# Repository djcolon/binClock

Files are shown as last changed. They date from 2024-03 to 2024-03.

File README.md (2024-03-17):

# binClock

**Daniel Colon - 19/02/2024**

binClock

A binary clock using an ESP8266 board with some 74HC595 shift registers to
drive LEDs.
Uses NTP to get time over the network.
Also has modes to show it's IP and ping-pong a led back and forth.

Built with an ESP32-C3 Mini, which I bought for 1.83
[here](https://www.aliexpress.com/item/1005005967641936.html)

[Built using PlatformIO](https://platformio.org/)

## Testing

To run tests you need to have configured the platformIO native environment.
See the [platformIO guides](https://piolabs.com/blog/insights/unit-testing-part-1.html)
for more detail.

After installation, run tests by navigating to `native > advanced > test` in the
platformIO sidebar.

## Board

The PCB and schematic do not include the LEDs. An 8-pin connector is offered,
as well as a mounting hole for the LED ground. The intention is to use a piece
of 2mm solid core copper to attach the LED ground to, with wires leading to an
8 pin connector which will plug into the PCB. The entire board can be powered
via the ESP32's USB-C connector.

## Images

The assembled binClock:

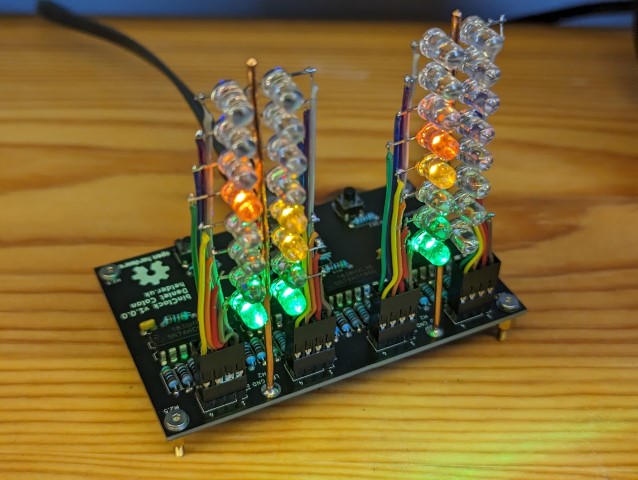
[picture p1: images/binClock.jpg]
The assembled binClock


The prototype:

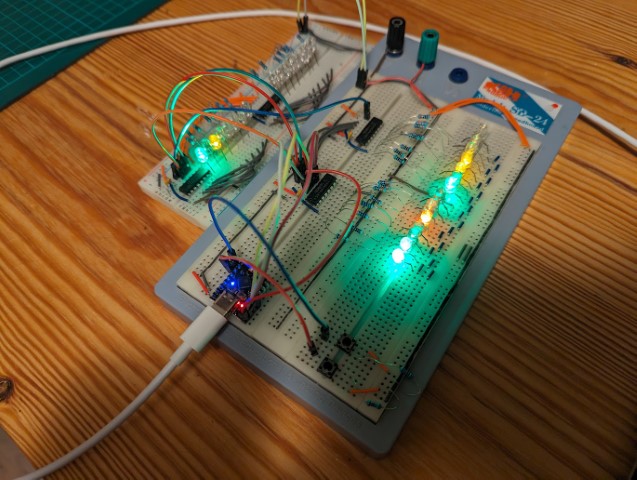
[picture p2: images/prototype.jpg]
The prototype


The schematic:

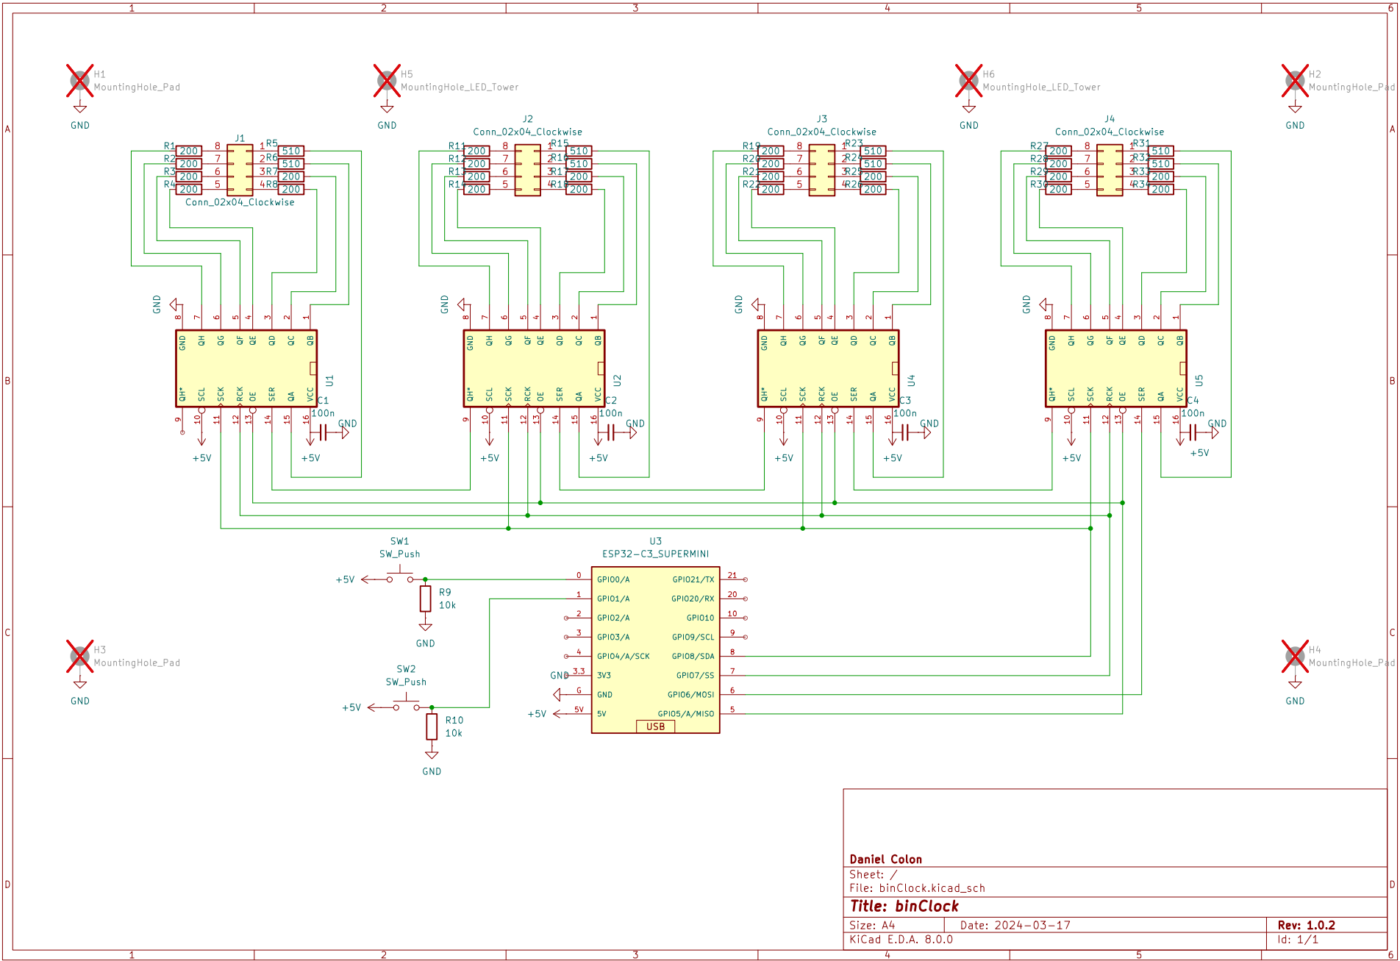
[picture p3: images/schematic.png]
The schematic


A preview of the PCB front:

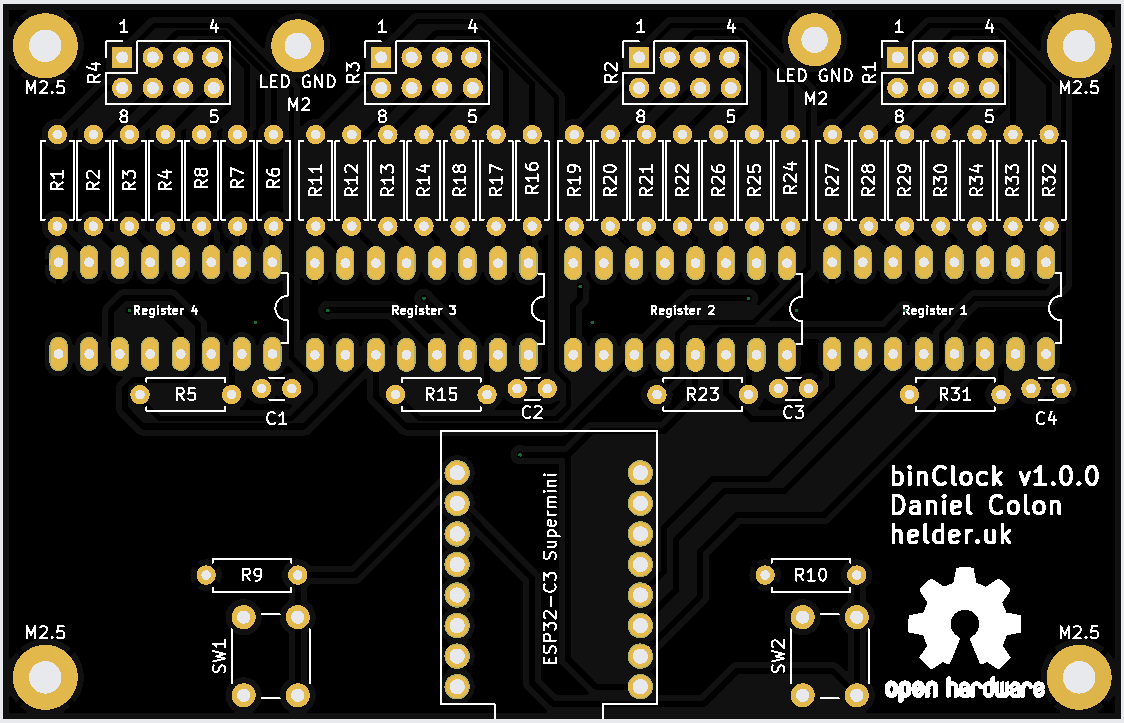
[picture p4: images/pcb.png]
The PCB preview


The devboard pinout.

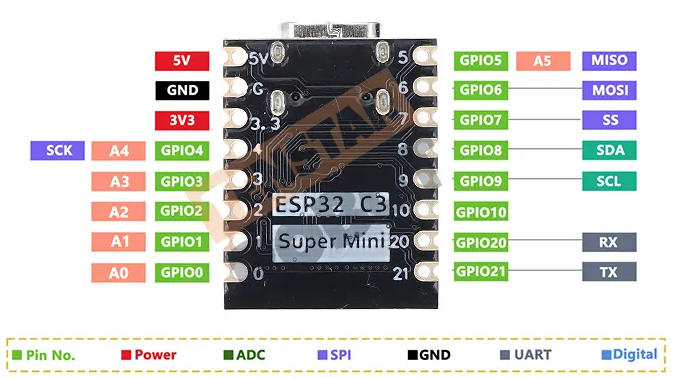
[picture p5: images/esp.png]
The devboard pinout


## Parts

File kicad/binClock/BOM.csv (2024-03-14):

Reference | Value | Qty | DNP
C1,C2,C3,C4 | 100n | 4
J1,J2,J3,J4 | Conn_02x04_Clockwise | 4
R1,R2,R3,R4,R7,R8,R11,R12,R13,R14,R17,R18,R19,R20,R21,R22,R25,R26,R27,R28,R29,R30,R33,R34 | 200 | 24
R5,R6,R15,R16,R23,R24,R31,R32 | 510 | 8
R9,R10 | 10k | 2
SW1,SW2 | SW_Push | 2
U1,U2,U4,U5 | 74HC595N | 4
U3 | ESP32-C3_SUPERMINI | 1

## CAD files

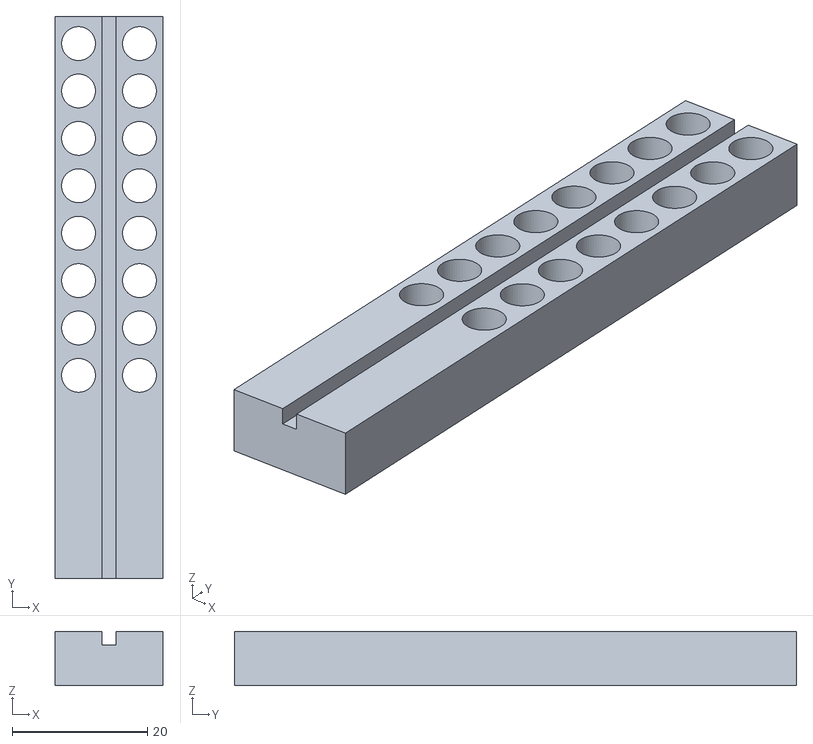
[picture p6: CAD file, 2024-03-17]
physical/tree_template.stl
16.0 x 83.0 x 8.00

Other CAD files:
physical/tree_template.f3d

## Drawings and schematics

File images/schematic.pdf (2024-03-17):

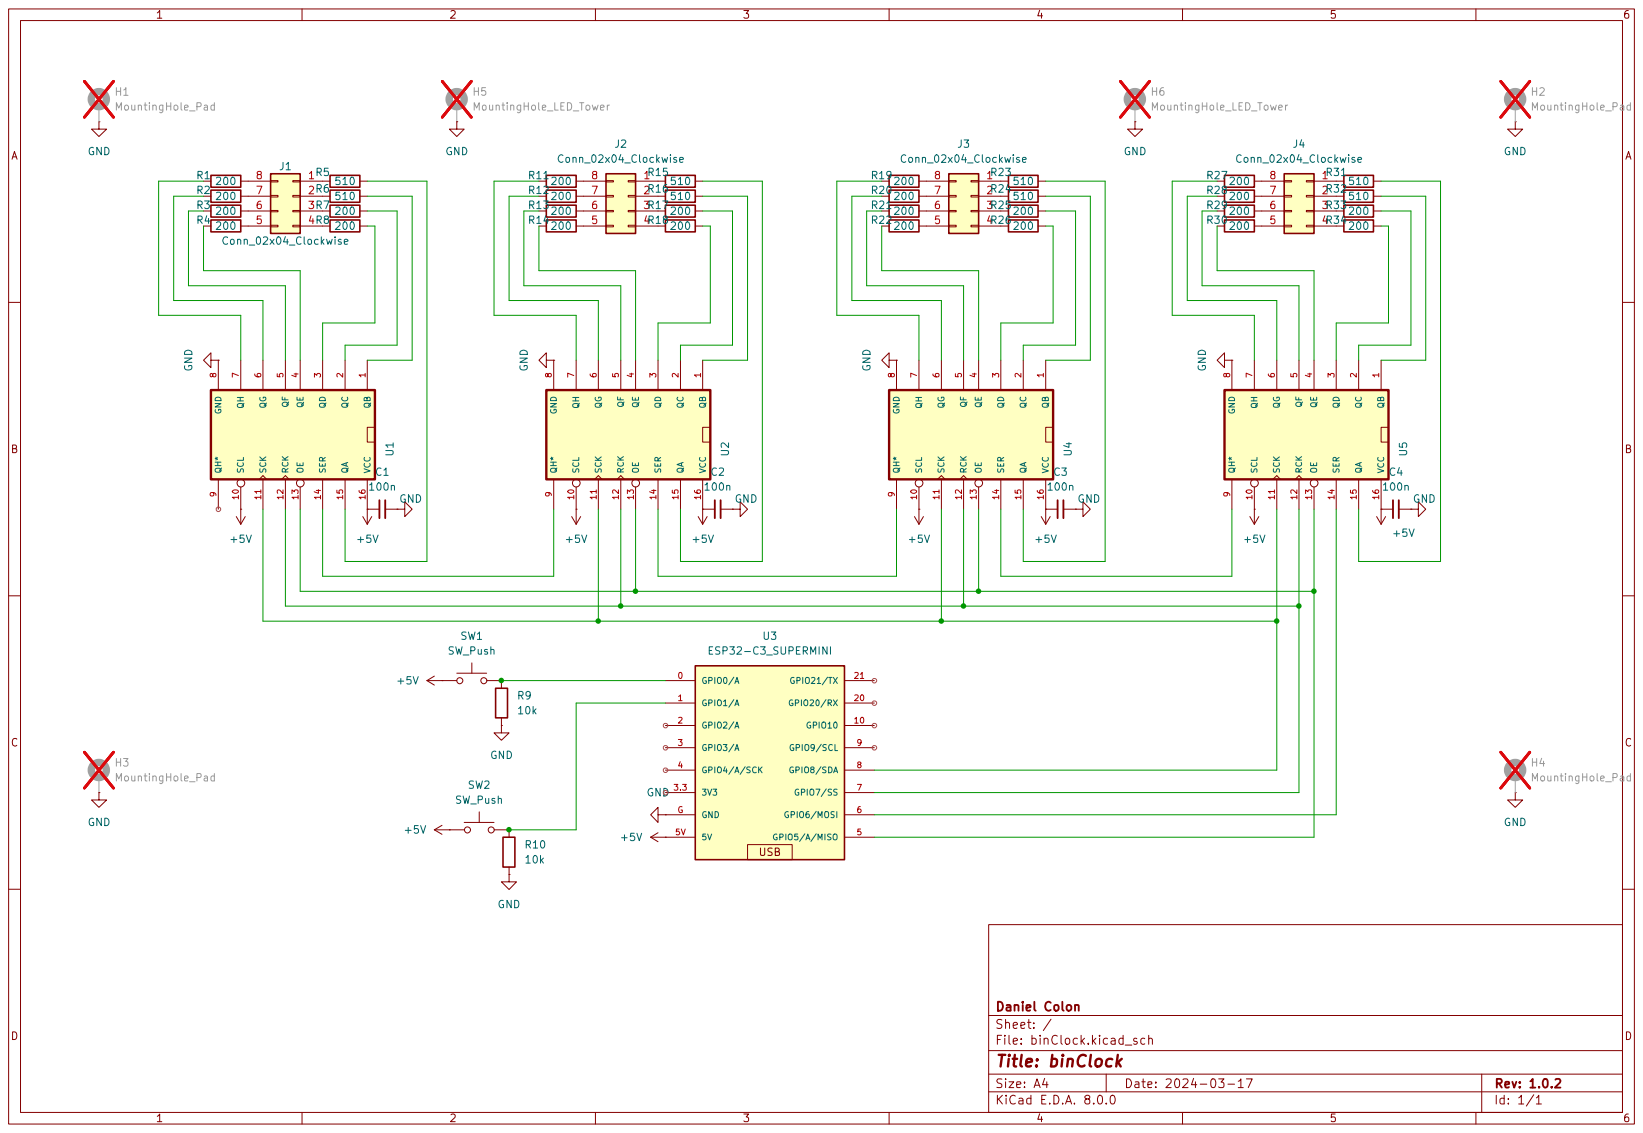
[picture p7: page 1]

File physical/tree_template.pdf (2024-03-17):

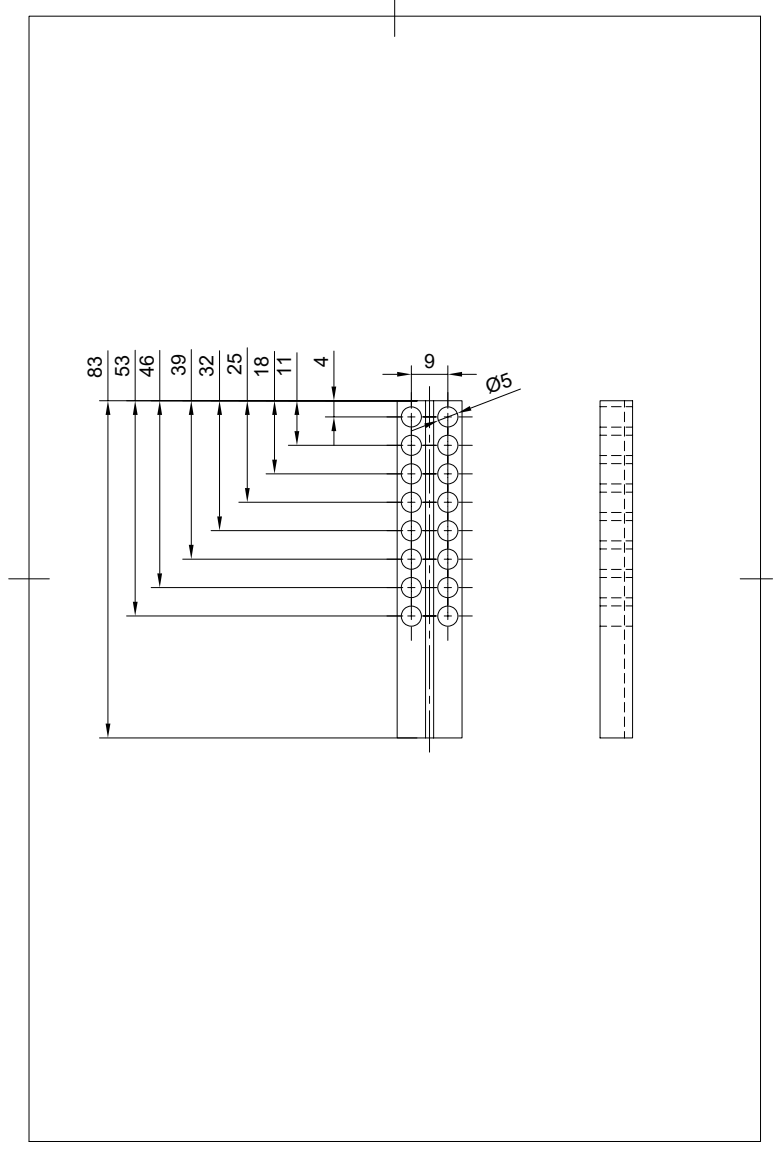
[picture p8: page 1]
Ø5 ⁴⁵³⁴⁶

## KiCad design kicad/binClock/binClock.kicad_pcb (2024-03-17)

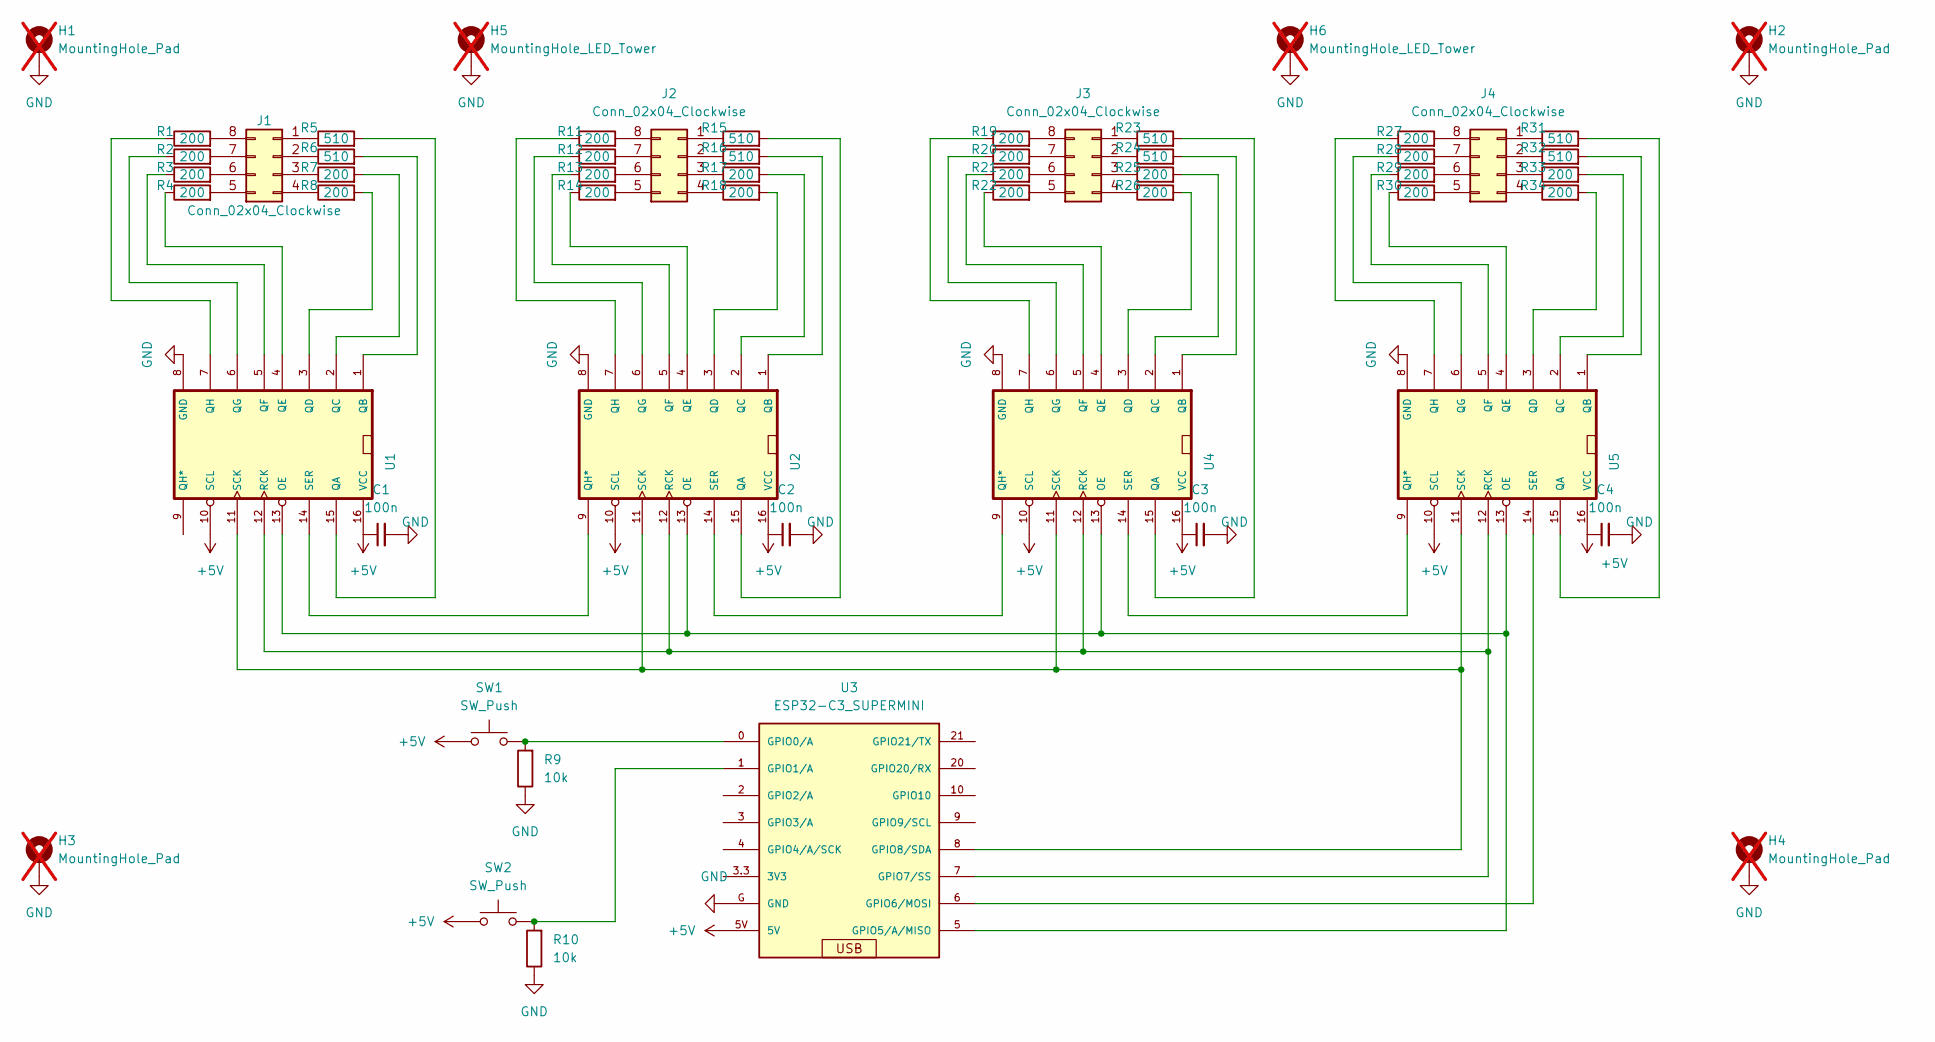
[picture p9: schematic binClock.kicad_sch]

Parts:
C1, C2, C3, C4: 100n; C_Disc_D3.0mm_W1.6mm_P2.50mm
H1, H2, H3, H4: MountingHole_Pad; MountingHole_2.7mm_M2.5_Pad_TopBottom; not fitted
H5, H6: MountingHole_LED_Tower; MountingHole_2.2mm_M2_Pad_TopBottom; not fitted
J1, J2, J3, J4: Conn_02x04_Clockwise; PinHeader_2x04_P2.54mm_Vertical_Clockwise
R1, R2, R3, R4, R7, R8, R11, R12, R13, R14, R17, R18, R19, R20, R21, R22, R25, R26, R27, R28, R29, R30, R33, R34: 200; R_Axial_DIN0207_L6.3mm_D2.5mm_P7.62mm_Horizontal
R5, R6, R15, R16, R23, R24, R31, R32: 510; R_Axial_DIN0207_L6.3mm_D2.5mm_P7.62mm_Horizontal
R9, R10: 10k; R_Axial_DIN0207_L6.3mm_D2.5mm_P7.62mm_Horizontal
SW1, SW2: SW_Push; SW_PUSH_6mm
U1, U2, U4, U5: 74HC595N; DIP16-2.54-20.32X5.84MM; MPN 74HC595N
U3: ESP32-C3_SUPERMINI; MODULE_ESP32-C3_SUPERMINI

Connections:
+5V: C1.1, C2.1, C3.1, C4.1, SW1.1, SW2.1, U1.10 (SCL), U1.16 (VCC), U2.10 (SCL), U2.16 (VCC), U3.5V, U4.10 (SCL), U4.16 (VCC), U5.10 (SCL), U5.16 (VCC)
GND: C1.2, C2.2, C3.2, C4.2, H1.1, H2.1, H3.1, H4.1, H5.1, H6.1, R9.1, R10.1, U1.8 (GND), U2.8 (GND), U3.G (GND), U4.8 (GND), U5.8 (GND)
unnamed: J1.1, R5.1
unnamed: J1.2, R6.1
unnamed: J1.3, R7.1
unnamed: J1.4, R8.1
unnamed: J1.5, R4.2
unnamed: J1.6, R3.2
unnamed: J1.7, R2.2
unnamed: J1.8, R1.2
unnamed: J2.1, R15.1
unnamed: J2.2, R16.1
unnamed: J2.3, R17.1
unnamed: J2.4, R18.1
unnamed: J2.5, R14.2
unnamed: J2.6, R13.2
unnamed: J2.7, R12.2
unnamed: J2.8, R11.2
unnamed: J3.1, R23.1
unnamed: J3.2, R24.1
unnamed: J3.3, R25.1
unnamed: J3.4, R26.1
unnamed: J3.5, R22.2
unnamed: J3.6, R21.2
unnamed: J3.7, R20.2
unnamed: J3.8, R19.2
unnamed: J4.1, R31.1
unnamed: J4.2, R32.1
unnamed: J4.3, R33.1
unnamed: J4.4, R34.1
unnamed: J4.5, R30.2
unnamed: J4.6, R29.2
unnamed: J4.7, R28.2
unnamed: J4.8, R27.2
unnamed: U1.13 (OE), U2.13 (OE), U3.5 (GPIO5/A/MISO), U4.13 (OE), U5.13 (OE)
unnamed: R5.2, U1.15 (QA)
unnamed: R6.2, U1.1 (QB)
unnamed: R7.2, U1.2 (QC)
unnamed: R8.2, U1.3 (QD)
unnamed: R4.1, U1.4 (QE)
unnamed: R3.1, U1.5 (QF)
unnamed: R2.1, U1.6 (QG)
unnamed: R1.1, U1.7 (QH)
unnamed: U1.12 (RCK), U2.12 (RCK), U3.7 (GPIO7/SS), U4.12 (RCK), U5.12 (RCK)
unnamed: U1.11 (SCK), U2.11 (SCK), U3.8 (GPIO8/SDA), U4.11 (SCK), U5.11 (SCK)
unnamed: U1.14 (SER), U2.9 (QH*)
unnamed: R15.2, U2.15 (QA)
unnamed: R16.2, U2.1 (QB)
unnamed: R17.2, U2.2 (QC)
unnamed: R18.2, U2.3 (QD)
unnamed: R14.1, U2.4 (QE)
unnamed: R13.1, U2.5 (QF)
unnamed: R12.1, U2.6 (QG)
unnamed: R11.1, U2.7 (QH)
unnamed: U2.14 (SER), U4.9 (QH*)
unnamed: R9.2, SW1.2, U3.0 (GPIO0/A)
unnamed: R10.2, SW2.2, U3.1 (GPIO1/A)
unnamed: U3.6 (GPIO6/MOSI), U5.14 (SER)
unnamed: R23.2, U4.15 (QA)
unnamed: R24.2, U4.1 (QB)
unnamed: R25.2, U4.2 (QC)
unnamed: R26.2, U4.3 (QD)
unnamed: R22.1, U4.4 (QE)
unnamed: R21.1, U4.5 (QF)
unnamed: R20.1, U4.6 (QG)
unnamed: R19.1, U4.7 (QH)
unnamed: U4.14 (SER), U5.9 (QH*)
unnamed: R31.2, U5.15 (QA)
unnamed: R32.2, U5.1 (QB)
unnamed: R33.2, U5.2 (QC)
unnamed: R34.2, U5.3 (QD)
unnamed: R30.1, U5.4 (QE)
unnamed: R29.1, U5.5 (QF)
unnamed: R28.1, U5.6 (QG)
unnamed: R27.1, U5.7 (QH)

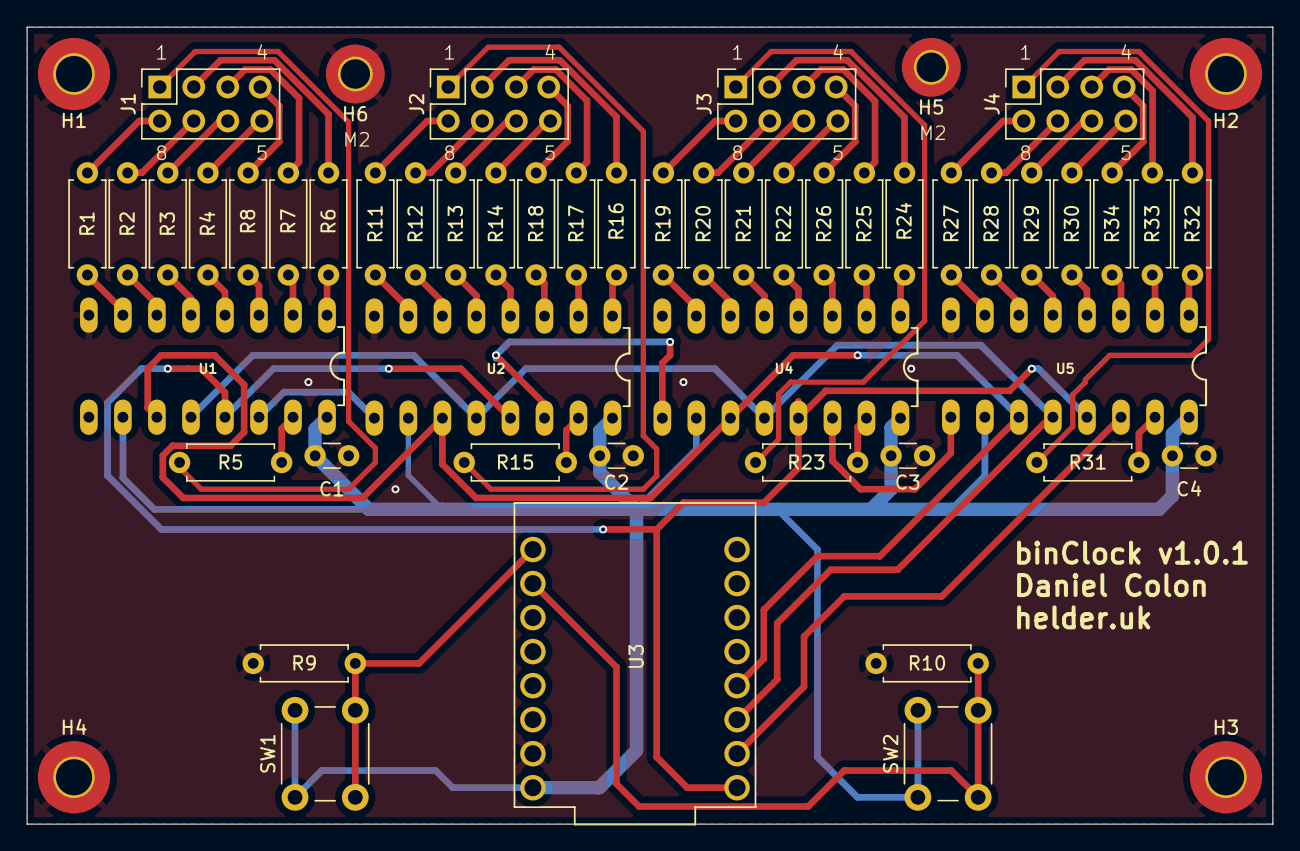
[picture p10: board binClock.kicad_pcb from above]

Board: 2 copper layers, 93.0 x 59.5 mm, 55 parts (0 on the bottom side), 75 nets.

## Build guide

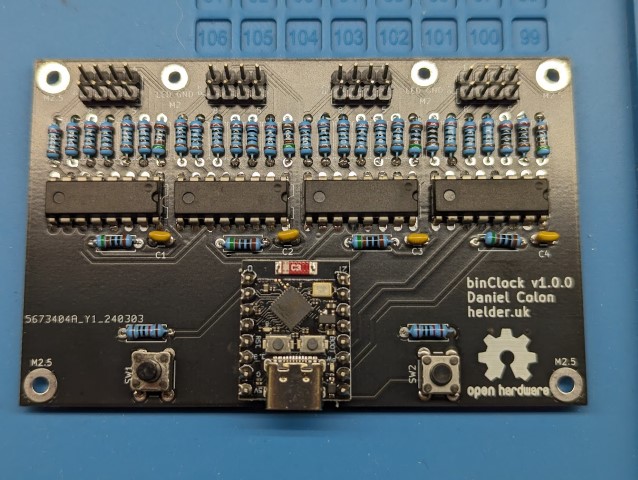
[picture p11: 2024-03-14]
images/assembled_pcb.jpg

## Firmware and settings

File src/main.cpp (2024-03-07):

// Libraries ///////////////////////////////////////////////////////////////////
#include <Arduino.h>
// WiFi
#include <WiFi.h>
#include <DNSServer.h>
#include <WebServer.h>
#include <WiFiManager.h> //https://github.com/tzapu/WiFiManager
#include <mDNS.h>
// Buttons
#include <EasyButton.h>
// Time
#include "time.h"
// Modes
#include "modeManager.cpp"

// Includes ////////////////////////////////////////////////////////////////////
#include "registers.h"
#include "modes/binClock.cpp"
#include "modes/pingPong.cpp"
#include "modes/showIp.cpp"
#include "modes/allOn.cpp"

// Definitions /////////////////////////////////////////////////////////////////
// Pins
#define INTERNAL_LED 8
#define CLOCK 8
#define LATCH 7
#define DATA 6
#define OE 5

// Buttons
#define BUTTON1 0
#define BUTTON2 1

// Flags
#define WRITEMSBFIRST
//#define DEBUG

// Config
#define HOSTNAME "binClock"

// Globals /////////////////////////////////////////////////////////////////////
EasyButton button1(BUTTON1);
EasyButton button2(BUTTON2);

Registers registers;

ModeManager modeManager;

// Other globals
// Brightness is inverted!
uint8_t brightness = 0;

// Functions ///////////////////////////////////////////////////////////////////

// Reads button states.
bool getButtonState(int buttonNumber) {
  switch(buttonNumber) {
    case 1:
      return digitalRead(BUTTON1) == HIGH;
    case 2:
      return digitalRead(BUTTON2) == HIGH;
    default:
      return false;
  }
}

// Shifts out our register in one go.
// Arduino shiftOut may because of weird glitches?
// Data is set on rising edge of clock. Hold time is 4.5ns (datasheet)
// This gives a rate of 222MHz, given that the chips is clocked at 26MHz, the
// factor 10 means we won't have to worry about timing. Chip runs faster than
// our program (especially with Arduino libs in between)!
void shiftOut32() {
  digitalWrite(LATCH, LOW);
  bool bit;
  for (uint8_t i = 0; i < 32; i++)
  {
    #ifdef WRITEMSBFIRST
      bit = !!(registers.asInt & (1 << (31 - i)));
    #else
      bit = !!(registers.asInt & (1 << i));
    #endif
    digitalWrite(DATA, bit);
    #ifdef DEBUG
      Serial.print(bit);
    #endif
    digitalWrite(CLOCK, HIGH);
    digitalWrite(CLOCK, LOW);
  }
  digitalWrite(LATCH, HIGH);
  #ifdef DEBUG
    Serial.print('\n');
  #endif
}

// Cycle through modes.
void onButton1Press() {
  Serial.println("Switching modes.");
  Serial.printf("Old mode: %s.\n", modeManager.getActiveMode()->getFriendlyName());
  modeManager.nextMode(registers);
  Serial.printf("New mode: %s.\n", modeManager.getActiveMode()->getFriendlyName());
}

// Cycle brightness.
void onButton2Press() {
  // 0 is full brightness, 255 is off.
  if(brightness == 255) {
    brightness = 0;
  } else {
    brightness = brightness + 64;
  }
  #ifdef DEBUG
    Serial.printf("Setting brightness to: %d.\n", brightness);
  #endif
  analogWrite(OE, brightness);
}

/**
 * Sets up mDNS so we have a name on the network.
*/
void setupMdns() {
    //initialize mDNS service
    esp_err_t err = mdns_init();
    if (err) {
        printf("MDNS Init failed: %d\n", err);
        return;
    }

    //set hostname
    mdns_hostname_set(HOSTNAME);
    //set default instance
    mdns_instance_name_set(HOSTNAME);
}

/**
 * Initialises modes. Add custom modes here.
*/
void setupModeManager() {
  modeManager.registerMode(new BinClock());
  modeManager.registerMode(new PingPong());
  modeManager.registerMode(new ShowIp());
  modeManager.registerMode(new AllOn());
  modeManager.setup(registers);
  registers.asInt = 0b00100000;
  shiftOut32();
}

/**
 * Called on boot.
*/
void setup() {
  // Pins
  pinMode(INTERNAL_LED, OUTPUT);
  pinMode(DATA, OUTPUT);
  pinMode(CLOCK, OUTPUT);
  pinMode(LATCH, OUTPUT);
  pinMode(OE, OUTPUT);
  pinMode(BUTTON1, INPUT);
  pinMode(BUTTON2, INPUT);
  digitalWrite(CLOCK, LOW);
  analogWrite(OE, brightness);
  // Set leds to init.
  registers.asInt = 0b00000001;
  shiftOut32();
  // Serial
  Serial.begin(115200);

  registers.asInt = 0b00000010;
  shiftOut32();
  // Set hostname.
  WiFi.hostname(HOSTNAME);
  // WiFi
  // Local initialization. Once its business is done, there is no need to keep
  // it around.
  WiFiManager wifiManager;
  // reset saved settings
  // Do we need to reset out wifi settings?
  if(getButtonState(1) && getButtonState(2)) {
    Serial.println("Resetting wifi settings.");
    wifiManager.resetSettings();
    ESP.restart();
  }
  // fetches ssid and pass from eeprom and tries to connect
  // if it does not connect it starts an access point with the specified name
  // here  "AutoConnectAP"
  // and goes into a blocking loop awaiting configuration
  wifiManager.autoConnect("binClock");
  // if you get here you have connected to the WiFi
  Serial.println("Connected to WiFi. Starting.");
  registers.asInt = 0b00000100;
  shiftOut32();
  // Print out the IP.
  Serial.print("IP address: ");
  Serial.println(WiFi.localIP());
  // Then set up MDNS
  setupMdns();
  // Set up button callbacks.
  button1.onPressed(onButton1Press);
  button2.onPressed(onButton2Press);
  // Set registers to 1 for starters.
  registers.asInt = 0b00001000;
  shiftOut32();
  // Initialise our modes.
  setupModeManager();
  // And we're done.
}

/**
 * Main application loop.
*/
void loop() {
  modeManager.loopActiveMode(registers, millis());
  shiftOut32();
  // Process buttons.
  button1.read();
  button2.read();
}

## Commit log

2024-02-22 Enabled all 4 registers with new extendd prototype.
2024-02-25 Added buttons to switch modes and reset wifi settings
    [main.cpp]
2024-02-25 Added image of prototype to README.
2024-02-25 Resetting registers on any mode switch.
    [main.cpp]
2024-02-26 Ported to ESP32-C3 Mini
2024-02-29 Started work on schematic and PCB
    [binClock.kicad_pcb, binClock.kicad_sch]
2024-03-01 Work on schematic, added chip image
    [binClock.kicad_sch]
2024-03-02 Finished schematic and board layout. Included gerbers. Ordered board from jlcpcb.
    [binClock-B_Cu.gbr, binClock-B_Mask.gbr, binClock-B_Paste.gbr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]
2024-03-02 Saved changes of fill areas after gerber generation
    [binClock.kicad_pcb]
2024-03-02 Changed pins to match new schematic. Added OE pin, and brightness settings.
2024-03-02 Added always on mode to troubleshoot LEDs. Shortened loop delays to increase button responsiveness.
    [main.cpp]
2024-03-02 Set binClock to default mode. Updated prototype photo.
2024-03-07 Fixed last bugs to get modeManager functional.
    [main.cpp]
2024-03-14 Added values to components. Added photo of assembled PCB and BOM
    [BOM.csv, binClock.kicad_pcb, binClock.kicad_sch]
2024-03-17 Added files for template used to create LED tree.
    [tree_template.f3d, tree_template.stl]
2024-03-17 Added center marks to holes on template
2024-03-17 Added centerline to wire in tree template PDF.
2024-03-17 Corrected error in schematic and recreated production files
    [binClock-B_Cu.gbl, binClock-B_Mask.gbr, binClock-B_Mask.gbs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]
2024-03-17 Added photo of working device.
2024-03-17 Saved last changes to board and board settings.
    [binClock.kicad_pcb, binClock.kicad_sch]
